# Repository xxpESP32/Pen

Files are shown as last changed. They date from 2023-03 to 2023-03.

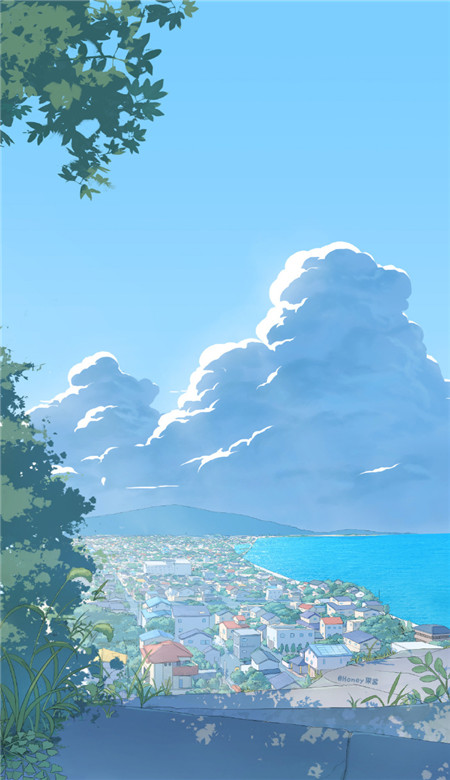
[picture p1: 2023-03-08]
智能笔_UG/Picture/16098342448596876.jpg

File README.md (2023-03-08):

# Pen
Pen
-----------------------------------------------------------------------
成果展示：
  F1031875C5988D5CCE9E4E356F72578C
  1486EAD7043B9777DE64F3FD1218BF45
  5BA2C4E5FA24933CE1F63FF3D8AA77C1
  985506B9519B345C8FC90BB7DC646DC1
  E5AF78B834A29C6D509D8185CFA4DB06

-----------------------------------------------------------------------

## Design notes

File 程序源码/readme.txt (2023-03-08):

/**
  **************************************************************************
  * @file     readme.txt 
  * @version  v2.1.2
  * @date     2022-08-16
  * @brief    readme
  **************************************************************************
  */

  this demo is based on the at-start board, in this demo, systick used for 
  delay function. led2~4 fresh fast or slow exchanged by user button.

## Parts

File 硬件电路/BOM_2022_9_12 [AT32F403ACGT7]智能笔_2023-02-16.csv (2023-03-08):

ID | Name | Designator | Footprint | Quantity | Manufacturer Part | Manufacturer | Supplier | Supplier Part | Price | Pins
1 | CR1220-2 | B1 | BAT-SMD_CR1220-2 | 1 | CR1220-2 | Q&J | LCSC | C70381 | 1.3512 | 2
2 | 22pF | C1,C2 | C0603 | 2 | CGA3E2C0G1H220JT0Y0N | TDK | LCSC | C338053 | 0.1529 | 2
3 | 10uF | C3,C10,C13,C14 | C0402 | 4 | GRJ155R60J106ME11D | muRata(村田) | LCSC | C469527 | 0.3983 | 2
4 | 10u | C4,C9 | C0603 | 2 |  |  |  |  |  | 2
5 | 100nF | C6,C7,C8,C15 | C0402 | 4 | GCM155R71C104KA55J | muRata(村田) | LCSC | C2655418 | 0.0395 | 2
6 | 22PF | C11,C12 | C0603 | 2 |  |  |  |  |  | 2
7 | 100nF | C16,C24,C25 | C0603 | 3 | CL10B104KC8NNNC | SAMSUNG | LCSC | C15725 | 0.0462 | 2
8 | 锂电池输入 | CN2 | CONN-TH_M2553V-02P | 1 | M2553V-02P | XFCN(台湾兴飞) | LCSC | C492449 | 0.413 | 2
9 | 1N5819HW-7-F | D1,D3 | SOD-123_L2.8-W1.8-LS3.7-FD | 2 | 1N5819HW-7-F | DIODES | LCSC | C82544 | 0.1569 | 2
10 | FPC-05F-8PH20 | FPC1 | FPC-SMD_8P-P0.50_FPC-05F-8PH20 | 1 | FPC-05F-8PH20 | XUNPU(讯普) | LCSC | C2856797 | 0.5247 | 10
11 | MH200V-11-05-1000 | H1 | HDR-TH_5P-P2.00-V-M-3 | 1 | MH200V-11-05-1000 | XFCN(台湾兴飞) | LCSC | C2839990 | 1.3401 | 5
12 | 204-10SURD/S530-A3 | LED1,LED2 | LED0805-RD | 2 | 204-10SURD/S530-A3 | EVERLIGHT | LCSC | C99772 | 0.2313 | 2
13 | WS2812B-B | LED6 | LED-SMD_4P-L5.0-W5.0-TL_WS2812B-B | 1 | WS2812B-B | Worldsemi | LCSC | C114586 | 0.5928 | 4
14 | 10k | R1,R3,R4,R6,R9,R23 | R0603 | 6 |  |  |  |  |  | 2
15 | 10K | R2,R13,R14,R18 | R0603 | 4 |  |  |  |  |  | 2
16 | 10kΩ | R5 | R0603 | 1 | SG73P1JTTD1002F | KOA Speer Elec | LCSC | C880254 | 0.0699 | 2
17 | 5kΩ | R7 | R0603 | 1 | RTT035001FTP | RALEC | LCSC | C166926 | 0.0133 | 2
18 | 220R | R8 | R0603 | 1 |  |  |  |  |  | 2
19 | 510Ω | R11 | R0603 | 1 | 0603WAJ0000T5E | UniOhm | LCSC | C15402 | 0.0067 | 2
20 | KH-2435-CAJ | SW1 | SW-SMD_KH-2435-CAJ | 1 | KH-2435-CAJ | kinghelm(金航标) | LCSC | C530669 | 0.2322 | 4
21 | TM-2023 | SW2 | SW-SMD_TM-2023-1 | 1 | TM-2023 | XKB Enterprise | LCSC | C318951 | 1.7524 | 8
22 | MK-12D18-G040 | SW3 | SW-TH_MK-12D18-G040 | 1 | MK-12D18-G040 | G-Switch | LCSC | C963202 | 0.6701 | 3
23 | AT32F403ACGT7 | U1 | LQFP-48_L7.0-W7.0-P0.50-LS9.0-BL | 1 | AT32F403ACGT7 | ARTERY | LCSC | C528437 | 12.77 | 48
24 | W25Q64FWSSIQ | U2 | SOIC-8_L5.3-W5.3-P1.27-LS8.0-BL | 1 | W25Q64FWSSIQ | Winbond Elec | LCSC | C783717 | 17 | 8
25 | AMS1117-3.3_C347256 | U3 | SOT-89_L4.5-W2.5-P1.50-LS4.2-BR | 1 | AMS1117-3.3 | Youtai Semiconductor Co., Ltd. | LCSC | C347256 | 0.2839 | 3
26 | TP4054_C668215 | U4 | SOT-23-5_L3.0-W1.7-P0.95-LS2.8-BL | 1 | TP4054 | UMW(Youtai Semiconductor Co., Ltd.) | LCSC | C668215 | 0.322 | 5
27 | ME6206A18PG | U7 | SOT-89-3_L4.5-W2.5-P1.50-LS4.2-BR | 1 | ME6206A18PG | Nanjing Micro One Elec | LCSC | C236708 | 0.4566 | 3
28 | CJ431_C3113 | U8 | SOT-23-3_L2.9-W1.6-P1.90-LS2.8-BR | 1 | CJ431 | CJ | LCSC | C3113 | 0.2165 | 3
29 | CH340N_C2977777 | U9 | SOP-8_L4.9-W3.9-P1.27-LS6.0-BL | 1 | CH340N | WCH(南京沁恒) | LCSC | C2977777 | 3.19 | 8
30 | TYPE-C16PIN | USB1 | USB-C-SMD_TYPE-C16PIN | 1 | TYPE-C16PIN | SHOU HAN | LCSC | C393939 | 1.3293 | 16
31 | 25mhz | X1 | OSC-SMD_4P-L3.2-W2.5-BL | 1 | XXCEELNANF-25MHZ | TAITIEN Elec | LCSC | C117869 | 1.2485 | 4
32 | - | X2 | OSC-SMD_L3.2-W1.5 | 1 | SF32K32768D31T-12.5 | TKD | LCSC | C271654 | 1.4145 | 2

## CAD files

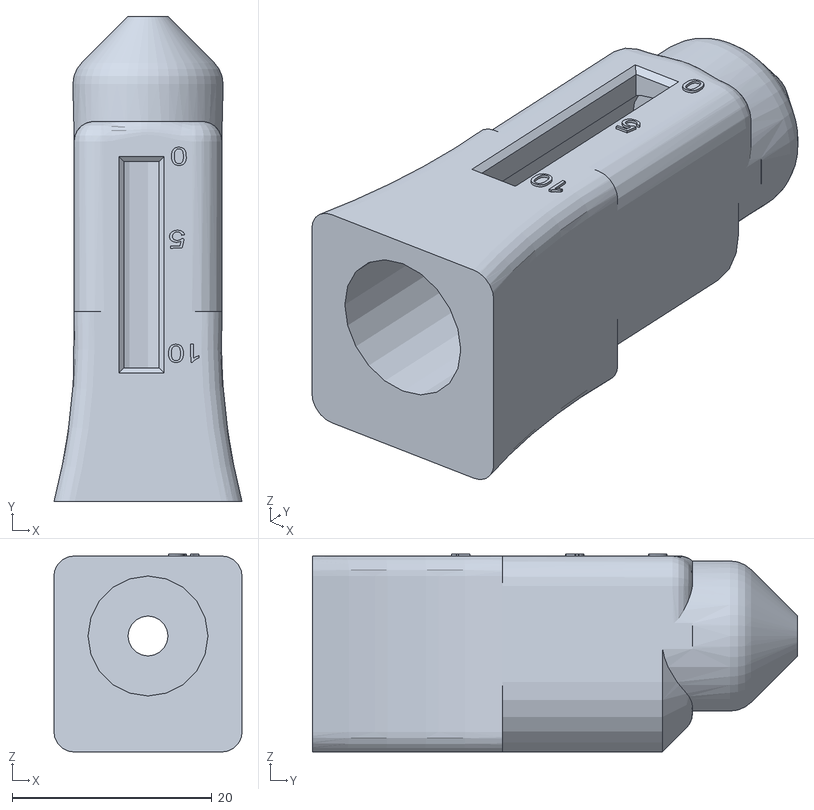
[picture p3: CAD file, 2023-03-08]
智能笔_UG/UG_1.2/STL/TOP.stl
18.8 x 48.5 x 19.8

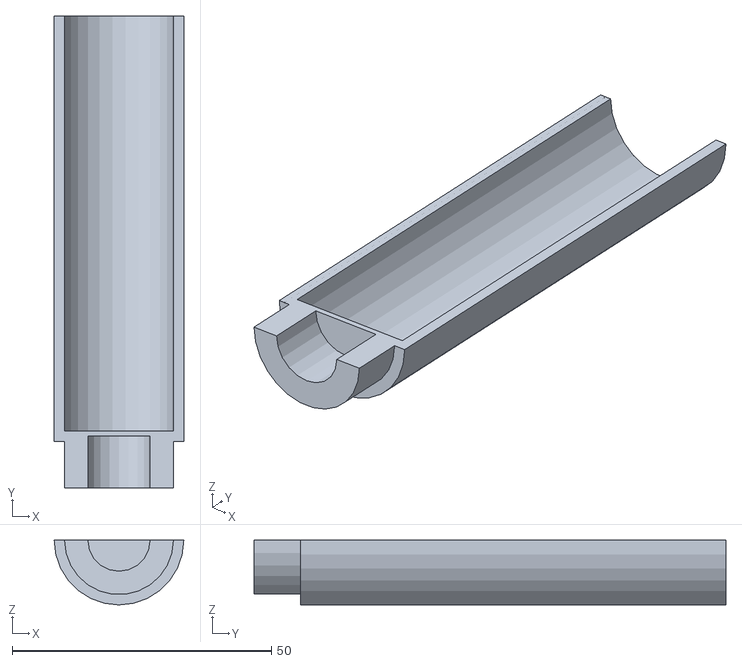
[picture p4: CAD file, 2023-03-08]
智能笔_UG/UI/NOW_STL/LEFT.stl
25.0 x 91.0 x 12.5

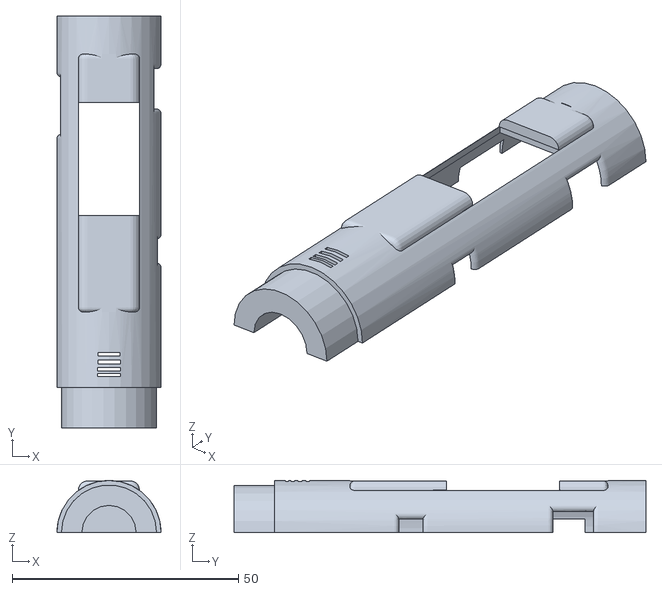
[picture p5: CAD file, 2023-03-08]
智能笔_UG/UI/STL/RIGHT.stl
23.0 x 91.0 x 11.5

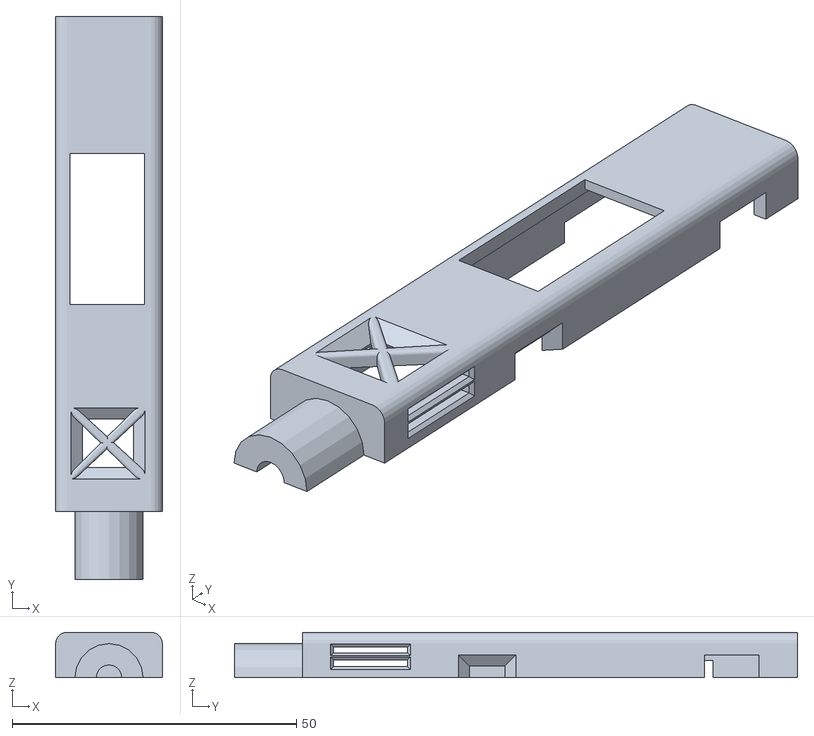
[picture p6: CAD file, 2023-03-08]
智能笔_UG/UI/STL_1.2/RIGHT1.stl
18.8 x 99.0 x 8.00

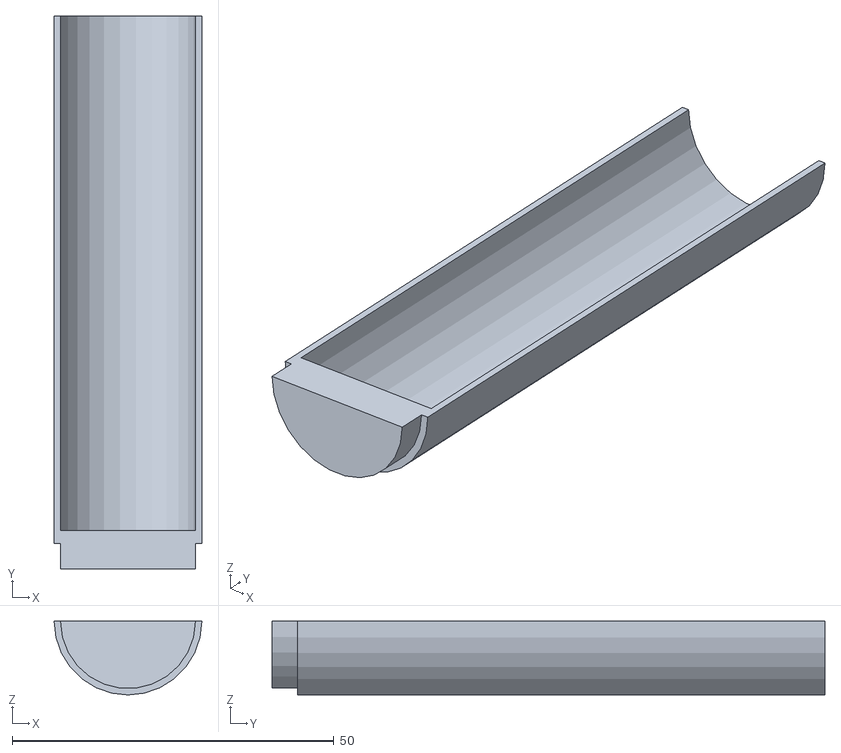
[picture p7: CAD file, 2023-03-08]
智能笔_UG/UI/左壳/LEFT.stl
23.0 x 86.0 x 11.5

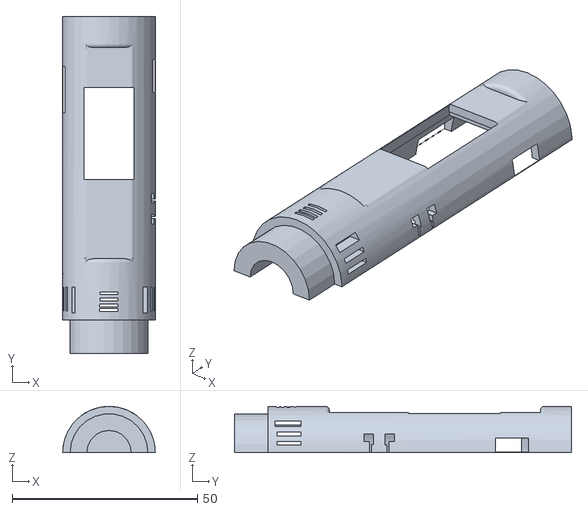
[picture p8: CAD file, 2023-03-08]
智能笔_UG/UI/NOW_STL/RIGHT.stl
25.0 x 91.0 x 12.5

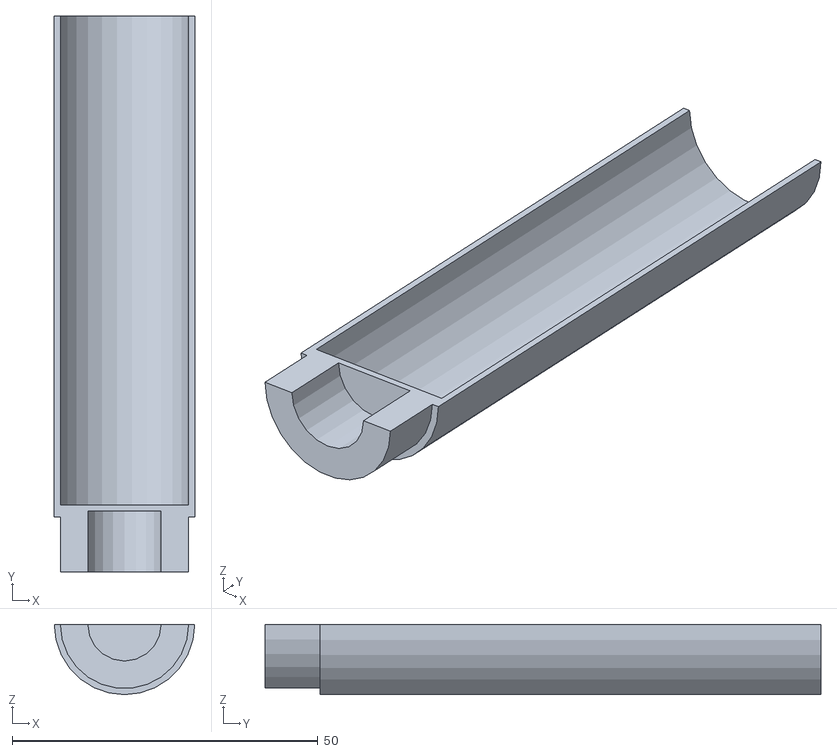
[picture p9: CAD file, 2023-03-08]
智能笔_UG/UI/STL/LEFT.stl
23.0 x 91.0 x 11.5

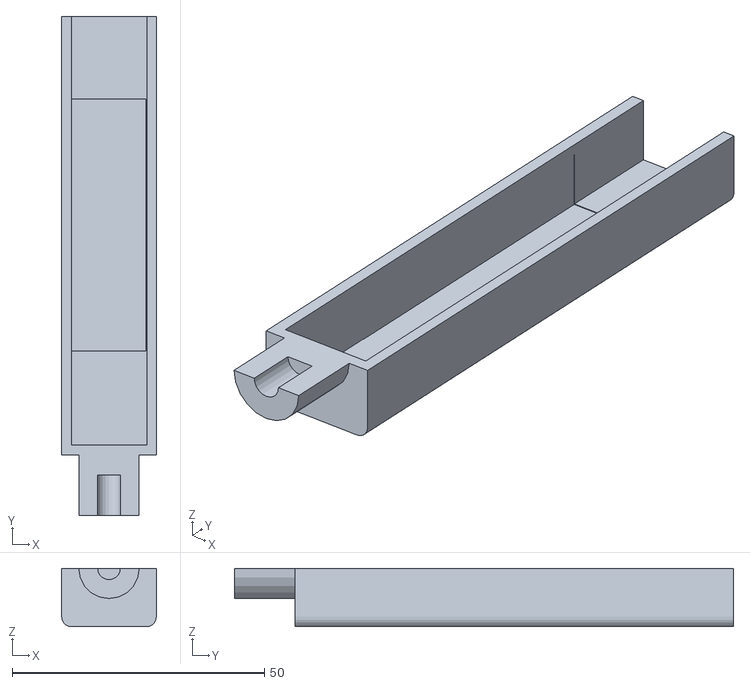
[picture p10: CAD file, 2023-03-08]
智能笔_UG/UI/STL_1.2/LEFT1.stl
18.8 x 99.0 x 11.6

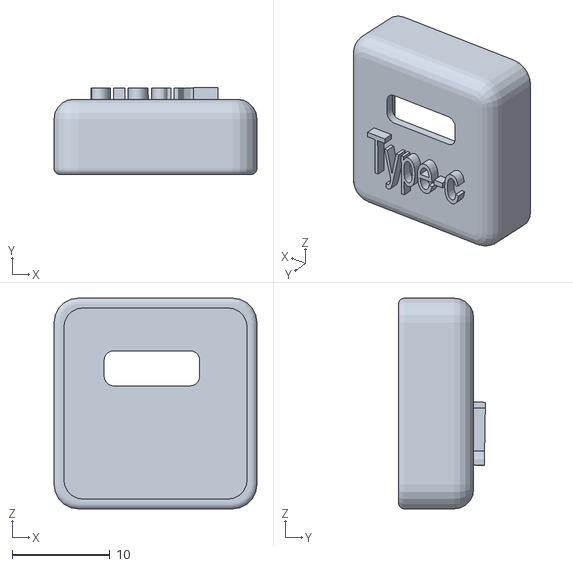
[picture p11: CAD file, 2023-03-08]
智能笔_UG/UG_1.2/STL/BOTTON.stl
20.8 x 8.91 x 21.6

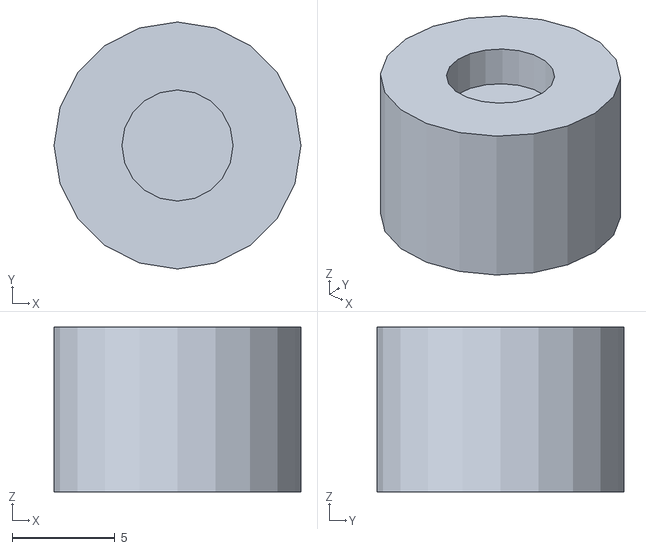
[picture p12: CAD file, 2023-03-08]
智能笔_UG/UI/NOW_STL/top_one.stl
12.0 x 12.0 x 8.00

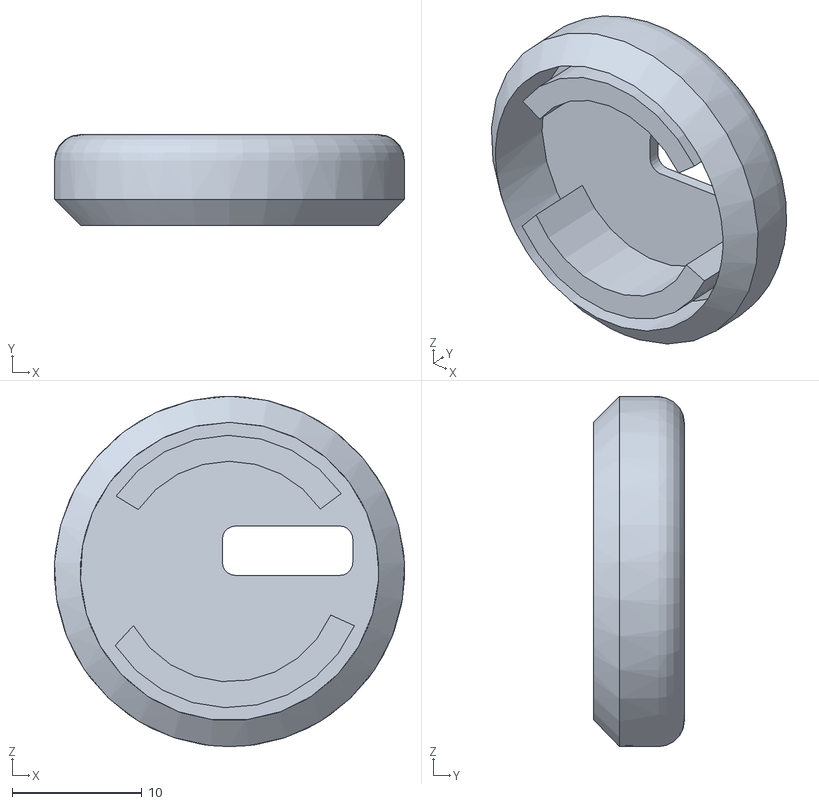
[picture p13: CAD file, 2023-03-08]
智能笔_UG/UI/STL/top.stl
27.0 x 7.00 x 27.0

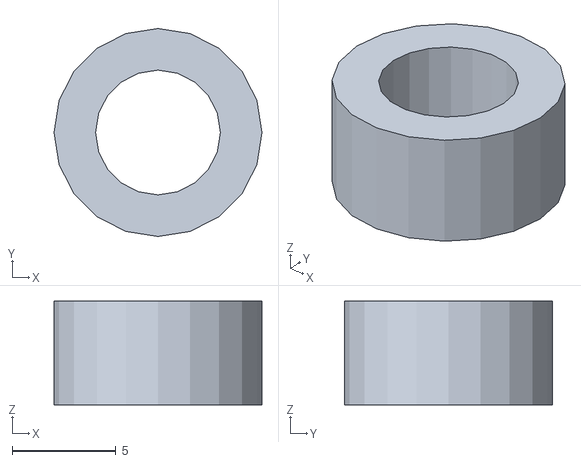
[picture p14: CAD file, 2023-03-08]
智能笔_UG/UI/NOW_STL/botton_one.stl
10.0 x 10.0 x 5.00

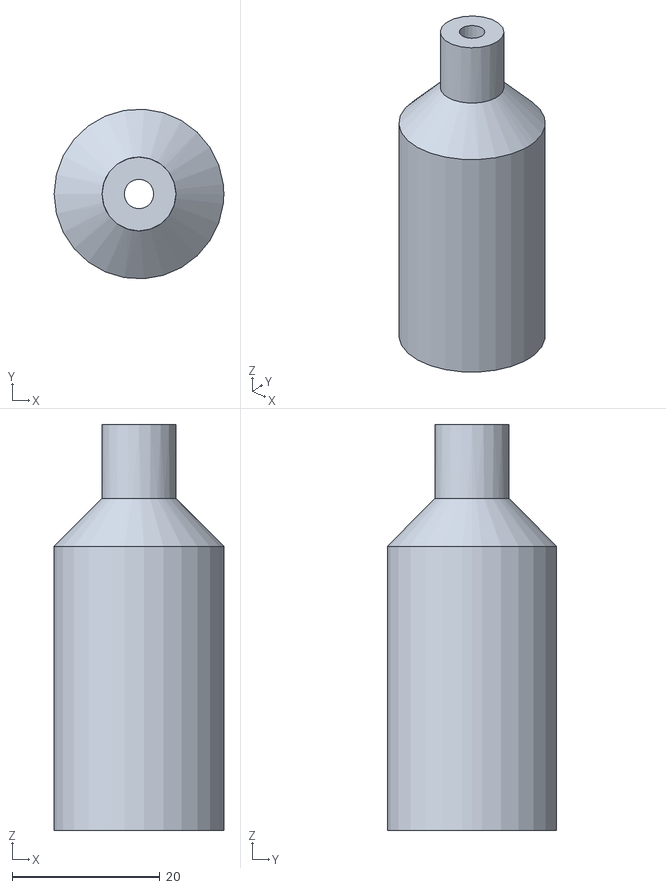
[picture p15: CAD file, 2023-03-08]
智能笔_UG/UI/STL/roller.stl
23.0 x 23.0 x 55.0

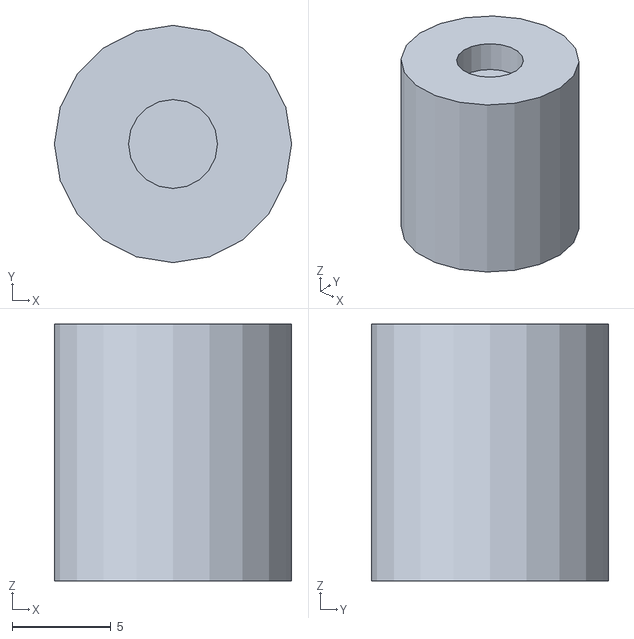
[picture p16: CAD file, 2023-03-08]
智能笔_UG/UI/NOW_STL/botton_Now.stl
12.0 x 12.0 x 13.0

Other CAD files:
智能笔_UG/UG_1.2/ALL/_asm1.prt
智能笔_UG/UG_1.2/BOTTON/BOTTON.prt
智能笔_UG/UG_1.2/LEFT/100N.prt
智能笔_UG/UG_1.2/LEFT/100N40714.prt
智能笔_UG/UG_1.2/LEFT/100N53370.prt
智能笔_UG/UG_1.2/LEFT/100N53398.prt
智能笔_UG/UG_1.2/LEFT/100NF.prt
智能笔_UG/UG_1.2/LEFT/100NF66194.prt
智能笔_UG/UG_1.2/LEFT/10K.prt
智能笔_UG/UG_1.2/LEFT/10K27630.prt
智能笔_UG/UG_1.2/LEFT/10K27658.prt
智能笔_UG/UG_1.2/LEFT/10K27686.prt
智能笔_UG/UG_1.2/LEFT/10K27714.prt
智能笔_UG/UG_1.2/LEFT/10K27742.prt
智能笔_UG/UG_1.2/LEFT/10K27798.prt
智能笔_UG/UG_1.2/LEFT/10K27826.prt
智能笔_UG/UG_1.2/LEFT/10K27854.prt
智能笔_UG/UG_1.2/LEFT/10K27910.prt
智能笔_UG/UG_1.2/LEFT/10K27938.prt
智能笔_UG/UG_1.2/LEFT/10U.prt
智能笔_UG/UG_1.2/LEFT/10U66054.prt
智能笔_UG/UG_1.2/LEFT/10U66110.prt
智能笔_UG/UG_1.2/LEFT/10U66138.prt
智能笔_UG/UG_1.2/LEFT/10U66166.prt
智能笔_UG/UG_1.2/LEFT/220R.prt
智能笔_UG/UG_1.2/LEFT/22PF.prt
智能笔_UG/UG_1.2/LEFT/22PF40602.prt
智能笔_UG/UG_1.2/LEFT/22PF40658.prt
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

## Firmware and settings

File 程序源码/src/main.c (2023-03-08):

#include "at32f403a_407_board.h"
#include "at32f403a_407_clock.h"
#include "lcd_init.h"
#include "lcd.h"
#include "pic.h"
#include "CST816.h"
#include "Timer.h"
#include "rtc.h"
#include "ws2812b.h"
#include "W25Q128.h"
#include "FreeRTOS.h"
#include "task.h"
#include "Timers.h"
#include "ADC.h"

#include "lvgl.h"
#include "lv_port_disp.h"
#include "lv_port_indev.h"
#include "LVGL_Main.h"
#include "LVGL_PORT_1.h"
#include "LVGL_PORT.h"
#include "LVGL_PORT_2.h"
#include "LVGL_PORT_3.h"
#include "LVGL_PORT_4.h"
#include "LVGL_PORT_5.h"
#include "LVGL_PORT_6.h"
#include "fontupd.h"
#include "text.h"	
#include "KEY_NVIC.h"
#include "WWDG.h"

/* 更新时间：2022/10/27
*更新内容：增加每日单词30个提醒
*           增加旋转界面设置。
*版本号：1.0.1
*/

/* 更新时间：2022/10/29
*更新内容：增加小学初中单词2100个
*           增加小学单词和四级单词设置显示。
*           FLW为四级单词  SOW为二级单词
*版本号：1.0.2
*/

/* 更新时间：2023/2/5
*更新内容：添加开机动画，设置添加恢复出厂设置
*版本号：1.0.3
*/

/* 更新时间：2023/2/15
*更新内容：添加独立看门狗，解决有时突然卡死的情况，卡死就复位
*版本号：1.0.4
*/

TaskHandle_t Handler_Task;
TaskHandle_t Handler_Task1;
TaskHandle_t Handler_Task2;


BaseType_t xReturn;
BaseType_t Task3Return;

StackType_t xIdle3Static[128];
StaticTask_t xIdleTCB;

StackType_t xITimeStatic[524];
StaticTask_t xITimeTCB;


uint8_t CC_BUFF[1024];
u16 W25Q128_ID;
uint8_t Reset_buff[10];

uint8_t ResetS_buff[10];
uint8_t Reset_buffs[10];
uint8_t YES_Buff[10];
uint8_t YES_val;

double virf_Value;

void vApplicationGetIdleTaskMemory( StaticTask_t ** ppxIdleTaskTCBBuffer,StackType_t ** ppxIdleTaskStackBuffer,uint32_t * pulIdleTaskStackSize ){
			*ppxIdleTaskTCBBuffer=&xIdleTCB;				
			*ppxIdleTaskStackBuffer=xIdle3Static;
			*pulIdleTaskStackSize=128;
}
void vApplicationGetTimerTaskMemory( StaticTask_t ** ppxTimerTaskTCBBuffer,
                                          StackType_t ** ppxTimerTaskStackBuffer,
                                              uint32_t * pulTimerTaskStackSize ){
			* ppxTimerTaskTCBBuffer=&xITimeTCB;																					
			* ppxTimerTaskStackBuffer=xITimeStatic;
			* pulTimerTaskStackSize	=524;																			
}
//空闲任务
void vApplicationIdleHook(void){
	
	while(1){
		
	}
	
}
//进入低功耗模式执行任务
void PreSleepProcessing(uint32_t ulExpectedldleTime){
  crm_periph_clock_enable(CRM_GPIOA_PERIPH_CLOCK,FALSE);
  crm_periph_clock_enable(CRM_GPIOB_PERIPH_CLOCK,FALSE);
	crm_periph_clock_enable(CRM_GPIOC_PERIPH_CLOCK,FALSE);
	crm_periph_clock_enable(CRM_GPIOD_PERIPH_CLOCK,FALSE);
	crm_periph_clock_enable(CRM_GPIOE_PERIPH_CLOCK,FALSE);
}

//退出低功耗模式执行任务
void PostSleepProcessing(uint32_t ulExpectedldleTime){
	crm_periph_clock_enable(CRM_GPIOA_PERIPH_CLOCK,TRUE);
	crm_periph_clock_enable(CRM_GPIOB_PERIPH_CLOCK,TRUE);
	crm_periph_clock_enable(CRM_GPIOC_PERIPH_CLOCK,TRUE);
	crm_periph_clock_enable(CRM_GPIOD_PERIPH_CLOCK,TRUE);
	crm_periph_clock_enable(CRM_GPIOE_PERIPH_CLOCK,TRUE);
	
}

void Task_1_Function(void* param)
{
			WS2812B_GPIO_Init();
			WS2812B_RESET();

		
		
			lv_init();
			lv_port_disp_init();
			lv_port_indev_init();
	

			
			//lv_obj_del(label_word);
	    
		
			LV_Main_Code();
			Timer_8_Init();
			Timer_Init();
			//读取英语单词上一次看的地方
			W25QXX_Read(CallBack,ADDR,sizeof(CallBack));
			Eglish_Flag=atoi(CallBack);
			WWCG_Init();//独立看门狗，每最大300ms喂一次狗
		while(1){
			  wdt_counter_reload();//喂狗
				lv_task_handler();			
			  voltage=ADC_GET_Value()*3.2;//更新时间 2022.12.6
			
		}		
	
}

/*
void Task_3_Function(void* param){
		//进入定时器
	while(1){  
			
		
	}	
}	*/

void Task_2_Function(void *param){
  taskENTER_CRITICAL();//进入临界区

	//创建任务一
	#if 1
	xReturn=xTaskCreate(Task_1_Function,"Task1",2800,NULL,1,&Handler_Task);
	
	if(xReturn== pdPASS){
		printf("Task Created successfully\r\n");	
	}else{
		printf("Failed to create a task\r\n");	
	}
	#endif
	//创建任务二
	#if 0
	Task3Return =xTaskCreate(Task_3_Function,"Task3",128,NULL,2,&Handler_Task2);
	if(Task3Return== pdPASS){
		printf("Task Created successfully\n");	
	}else{
		printf("Failed to create a task\n");	
	}
	#endif
	//删除首任务，释放内存
	vTaskDelete(Handler_Task1);
	
	taskEXIT_CRITICAL();//退出临界区
	while(1);
}


int main(void)
{

  system_clock_config();
  at32_board_init();
	NVIC_SetPriorityGrouping(NVIC_PRIORITY_GROUP_2);
	uart_print_init(115200);
	alarm_init();
	W25Q128_Init();	
	ADC_Init();
	LCD_Init();	
	LCD_Fill(0,0,160,80,WHITE);

	//update_font(0,20,12);//更新字库
	//串口下载字库
//更新时间2022.11.29 左键开机进行单词烧录
	KEY_Init();
	if(KEY0 ==0){
		update_font_word(0,20,12);//更新字库
		while(font_word_init())
		{
			
			printf("NO FONT!\r\n");

			LCD_ShowString(0,0,(u8*)"Font Error!",RED,WHITE,12,0);
			Delay_ms(1000);
			LCD_ShowString(0,0,(u8*)"Start Updating Font!",RED,WHITE,12,0);
			printf("UPDATA_XWP...\r\n");
			update_font_word(0,20,12);//更新字库
			break;
		}
	}

		//更新 2022.11.29 获取自己单词
	W25QXX_Read(Own_buff,1024*1024*144+9,sizeof(Own_buff));
	
  sprintf(DMA_Buff_1,"%s",Own_buff);
	printf("%s\r\n",DMA_Buff_1);	
//更新2022.11.29       END
	#if 1
	while(font_init())
	{
	  
		printf("NO FONT!\r\n");

		LCD_ShowString(0,0,(u8*)"Font Error!",RED,WHITE,12,0);
		Delay_ms(1000);
		LCD_ShowString(0,0,(u8*)"Start Updating Font!",RED,WHITE,12,0);
		printf("开始更新字库...\r\n");
		update_font(0,20,12);//更新字库
		break;
	}
	printf("ADC_Begin...\r\n");
	
			//读取BUFF的值
			W25QXX_Read(ResetS_buff,1024*1024*126,sizeof(ResetS_buff));
			YES_val=atoi(ResetS_buff);
			rtc_time_get();
			printf("Hour=%d\r\n",calendar.date);
    if(YES_val != calendar.date){	
			sprintf(YES_Buff,"%d",calendar.date);
			W25QXX_Write(YES_Buff,1024*1024*126,sizeof(YES_Buff));
			sprintf(word_b,"%d",0);
			W25QXX_Write(word_b,Word_Flag_Addr,sizeof(word_b));
			printf("INPUT");			
		}
		sprintf(YES_Buff,"%d",calendar.date);
		W25QXX_Write(YES_Buff,1024*1024*126,sizeof(YES_Buff));
		
		W25QXX_Read(LV_R_Wrod_Buff,1024*1024*100,sizeof(LV_R_Wrod_Buff));
		Wrod_Ch_Flag=atoi(LV_R_Wrod_Buff);
		printf("NUMBER[1]=%d\n",Wrod_Ch_Flag);
		
		
		
		Timer_2_Init();
 #endif
	xTaskCreate(Task_2_Function,"Task2",3000,NULL,1,&Handler_Task1);
	
	vTaskStartScheduler();
   
  while(1)
  {


  }
}

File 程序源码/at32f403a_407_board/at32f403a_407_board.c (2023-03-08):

#include "at32f403a_407_board.h"

#define STEP_DELAY_MS 50

/* delay variable */
static __IO uint32_t fac_us;
static __IO uint32_t fac_ms;
#if 1
dma_init_type DMA_USART;
u8 DMA_Buff[1028];
u8 DMA_Buff_1[1028];
u8 GBK_BUF_Flag=2;
#endif

/* support printf function, usemicrolib is unnecessary */
#if (__ARMCC_VERSION > 6000000)
  __asm (".global __use_no_semihosting\n\t");
  void _sys_exit(int x)
  {
    x = x;
  }
  /* __use_no_semihosting was requested, but _ttywrch was */
  void _ttywrch(int ch)
  {
    ch = ch;
  }
  FILE __stdout;
#else
 #ifdef __CC_ARM
  #pragma import(__use_no_semihosting)
  struct __FILE
  {
    int handle;
  };
  FILE __stdout;
  void _sys_exit(int x)
  {
    x = x;
  }
  /* __use_no_semihosting was requested, but _ttywrch was */
  void _ttywrch(int ch)
  {
    ch = ch;
  }
 #endif
#endif

#if defined (__GNUC__) && !defined (__clang__)
  #define PUTCHAR_PROTOTYPE int __io_putchar(int ch)
#else
  #define PUTCHAR_PROTOTYPE int fputc(int ch, FILE *f)
#endif

/**
  * @brief  retargets the c library printf function to the usart.
  * @param  none
  * @retval none
  */
PUTCHAR_PROTOTYPE
{
  while(usart_flag_get(PRINT_UART, USART_TDBE_FLAG) == RESET);
  usart_data_transmit(PRINT_UART, ch);
  return ch;
}

#if defined (__GNUC__) && !defined (__clang__)
int _write(int fd, char *pbuffer, int size)
{
  for(int i = 0; i < size; i ++)
  {
    __io_putchar(*pbuffer++);
  }

  return size;
}
#endif

/**
  * @brief  initialize uart
  * @param  baudrate: uart baudrate
  * @retval none
  */
void uart_print_init(uint32_t baudrate)
{
  gpio_init_type gpio_init_struct;

#if defined (__GNUC__) && !defined (__clang__)
  setvbuf(stdout, NULL, _IONBF, 0);
#endif

  /* enable the uart and gpio clock */
  crm_periph_clock_enable(PRINT_UART_CRM_CLK, TRUE);
  crm_periph_clock_enable(PRINT_UART_TX_GPIO_CRM_CLK, TRUE);

  gpio_default_para_init(&gpio_init_struct);

  /* configure the uart tx pin */
  gpio_init_struct.gpio_drive_strength = GPIO_DRIVE_STRENGTH_STRONGER;
  gpio_init_struct.gpio_out_type  = GPIO_OUTPUT_PUSH_PULL;
  gpio_init_struct.gpio_mode = GPIO_MODE_MUX;
  gpio_init_struct.gpio_pins = PRINT_UART_TX_PIN;
  gpio_init_struct.gpio_pull = GPIO_PULL_NONE;
  gpio_init(PRINT_UART_TX_GPIO, &gpio_init_struct);

	/* configure the uart rx pin */
	gpio_init_struct.gpio_drive_strength =GPIO_DRIVE_STRENGTH_STRONGER;
	gpio_init_struct.gpio_mode =GPIO_MODE_INPUT;
	gpio_init_struct.gpio_out_type =GPIO_OUTPUT_PUSH_PULL;
	gpio_init_struct.gpio_pins = PRINT_UART_RX_PIN;
	gpio_init_struct.gpio_pull = GPIO_PULL_UP;
	gpio_init(PRINT_UART_TX_GPIO, &gpio_init_struct);
	
	/* configure uart NVIC */
	nvic_irq_enable(USART1_IRQn,2,2);
	usart_interrupt_enable(USART1,USART_IDLE_INT,TRUE);
	//usart_flag_clear(USART1,USART_TDC_FLAG);
  /* configure uart param */
  usart_init(PRINT_UART, baudrate, USART_DATA_8BITS, USART_STOP_1_BIT);
  usart_transmitter_enable(PRINT_UART, TRUE);
	usart_receiver_enable(PRINT_UART,TRUE);

	usart_dma_receiver_enable(USART1,TRUE);
  usart_enable(PRINT_UART, TRUE);
		DMA_USART_Init((u32)(&USART1->dt),(u32)DMA_Buff,1028);

	
}
void DMA_USART_Init(u32 pddr,u32 mddr,u16 buff_size){
	crm_periph_clock_enable(CRM_DMA1_PERIPH_CLOCK,TRUE);
	dma_reset(DMA1_CHANNEL5);
	dma_default_para_init(&DMA_USART);
	
	DMA_USART.peripheral_base_addr =pddr;
	DMA_USART.memory_base_addr =mddr;
	DMA_USART.buffer_size = buff_size;
	DMA_USART.direction = DMA_DIR_PERIPHERAL_TO_MEMORY;
	DMA_USART.loop_mode_enable =TRUE;
	DMA_USART.memory_data_width =DMA_MEMORY_DATA_WIDTH_BYTE;
	DMA_USART.peripheral_data_width =DMA_PERIPHERAL_DATA_WIDTH_BYTE;
	DMA_USART.memory_inc_enable = TRUE;
	DMA_USART.peripheral_inc_enable =FALSE;
	DMA_USART.priority =DMA_PRIORITY_VERY_HIGH;
	dma_init(DMA1_CHANNEL5,&DMA_USART);
	
	nvic_irq_enable(DMA1_Channel5_IRQn,0,0);
  dma_interrupt_enable(DMA1_CHANNEL5,DMA_FDT_INT,TRUE);
	dma_channel_enable(DMA1_CHANNEL5,TRUE);
	//dma_flexible_config(DMA1, FLEX_CHANNEL5, DMA_FLEXIBLE_UART1_RX);
}
void DMA_Enable(void)
{
	//DMA_USART_Init((u32)(&USART1->dt),(u32)DMA_Buff,1028);
	dma_channel_enable(DMA1_CHANNEL5,FALSE);
	//DMA_USART_Init((u32)(&USART1->dt),(u32)DMA_Buff,1028);
	GBK_BUF_Flag=0;
	dma_data_number_set(DMA1_CHANNEL5,1028);
	dma_channel_enable(DMA1_CHANNEL5,TRUE);
}


void USART1_IRQHandler(void){
		 u8 clear=clear;
	if(usart_flag_get(USART1,USART_IDLEF_FLAG)!= RESET){
		 //usart_flag_clear(USART1,USART_IDLEF_FLAG);
		 clear=USART1->sts;
		 clear=USART1->dt;
		 DMA_Enable();
	}
	
	
}


void at32_board_init()
{
  /* initialize delay function */
  delay_init();

  /* configure led in at_start_board */
  at32_led_init(LED2);
  at32_led_init(LED3);
  at32_led_init(LED4);
  at32_led_off(LED2);
  at32_led_off(LED3);
  at32_led_off(LED4);

  /* configure button in at_start board */
  at32_button_init();
}
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

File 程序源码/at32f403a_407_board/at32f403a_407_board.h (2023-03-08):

#ifndef __AT32F403A_407_BOARD_H
#define __AT32F403A_407_BOARD_H

#ifdef __cplusplus
extern "C" {
#endif

#include "stdio.h"
#include "at32f403a_407.h"

/** @addtogroup AT32F403A_407_board
  * @{
  */

/** @addtogroup BOARD
  * @{
  */

/** @defgroup BOARD_pins_definition
  * @{
  */

/**
  * this header include define support list:
  * 1. at-start-f403a v1.x board
  * 2. at-start-f407 v1.x board
  * if define AT_START_F403A_V1, the header file support at-start-f403a v1.x board
  * if define AT_START_F407_V1, the header file support at-start-f407 v1.x board
  */

#if !defined (AT_START_F403A_V1)&& !defined (AT_START_F407_V1)
#error "please select first the board at-start device used in your application (in at32f403a_407_board.h file)"
#endif

/******************** define led ********************/
typedef enum
{
  LED2                                   = 0,
  LED3                                   = 1,
  LED4                                   = 2
} led_type;

#define LED_NUM                          3

#if defined (AT_START_F403A_V1) || defined (AT_START_F407_V1)
#define LED2_PIN                         GPIO_PINS_0
#define LED2_GPIO                        GPIOA
#define LED2_GPIO_CRM_CLK                CRM_GPIOA_PERIPH_CLOCK

#define LED3_PIN                         GPIO_PINS_1
#define LED3_GPIO                        GPIOA
#define LED3_GPIO_CRM_CLK                CRM_GPIOA_PERIPH_CLOCK

#define LED4_PIN                         GPIO_PINS_2
#define LED4_GPIO                        GPIOA
#define LED4_GPIO_CRM_CLK                CRM_GPIOA_PERIPH_CLOCK
#endif

/**************** define print uart ******************/
#define PRINT_UART                       USART1
#define PRINT_UART_CRM_CLK               CRM_USART1_PERIPH_CLOCK
#define PRINT_UART_TX_PIN                GPIO_PINS_9
#define PRINT_UART_TX_GPIO               GPIOA
#define PRINT_UART_TX_GPIO_CRM_CLK       CRM_GPIOA_PERIPH_CLOCK
#define PRINT_UART_RX_PIN                GPIO_PINS_10;

extern u8 DMA_Buff[1028];
extern u8 DMA_Buff_1[1028];
extern u8 GBK_BUF_Flag;
/******************* define button *******************/
typedef enum
{
  USER_BUTTON                            = 0,
  NO_BUTTON                              = 1
} button_type;

#define USER_BUTTON_PIN                  GPIO_PINS_2
#define USER_BUTTON_PORT                 GPIOB
#define USER_BUTTON_CRM_CLK              CRM_GPIOB_PERIPH_CLOCK

/**
  * @}
  */

/** @defgroup BOARD_exported_functions
  * @{
  */

/******************** functions ********************/
void at32_board_init(void);
void DMA_USART_Init(u32 pddr,u32 mddr,u16 buff_size);
/* led operation function */
void at32_led_init(led_type led);
void at32_led_on(led_type led);
void at32_led_off(led_type led);
void at32_led_toggle(led_type led);

/* button operation function */
void at32_button_init(void);
button_type at32_button_press(void);
uint8_t at32_button_state(void);

/* delay function */
void delay_init(void);
void delay_us(uint32_t nus);
void delay_ms(uint16_t nms);
void delay_sec(uint16_t sec);
void Delay_ms(uint16_t nms);
/* printf uart init function */
void uart_print_init(uint32_t baudrate);
void Delay_US(uint32_t nus);
/**
  * @}
  */

/**
  * @}
  */

/**
  * @}
  */

#ifdef __cplusplus
}
#endif

#endif
